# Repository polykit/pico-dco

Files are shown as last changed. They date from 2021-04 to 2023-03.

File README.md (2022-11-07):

# Raspberry Pi Pico Polyphonic DCO

This repository contains source code, schematics and PCB for a digitally controlled oscillator (DCO) with up to 6 voices which are driven by a Raspberry Pi Pico. It uses PIO to generate a highly accurate frequency which is controlled by USB or serial MIDI. The analog oscillator part is based on the Juno 106 and generates sawtooth and square wave signal with a 10Vpp amplitude. Amplitude compensation is done by a smoothed PWM signal coming from the Pico.

## Key features

- Digitally controlled analog oscillator using a Raspberry Pi Pico
- Up to six voices
- Voice stacking
- Detuning of voices
- Frequency modulation (FM)
- Separate gate signal
- DIN MIDI serial input
- USB MIDI input
- MIDI pitch bend
- Portamento with adjustable speed

This is how it sounds: [Ramp sample](https://soundcloud.com/polykit/pico-dco-ramp) [Pulse sample](https://soundcloud.com/polykit/pico-dco-pulse) [Polyphonic sample](https://soundcloud.com/polykit/pico-dco-polyphonic)

I use the DCO in my Polykit-6 polyphonic synthesizer, see https://www.youtube.com/watch?v=vj-DSh6yfM0 and https://www.youtube.com/watch?v=go1mErOdtsU

## Schematics and PCB

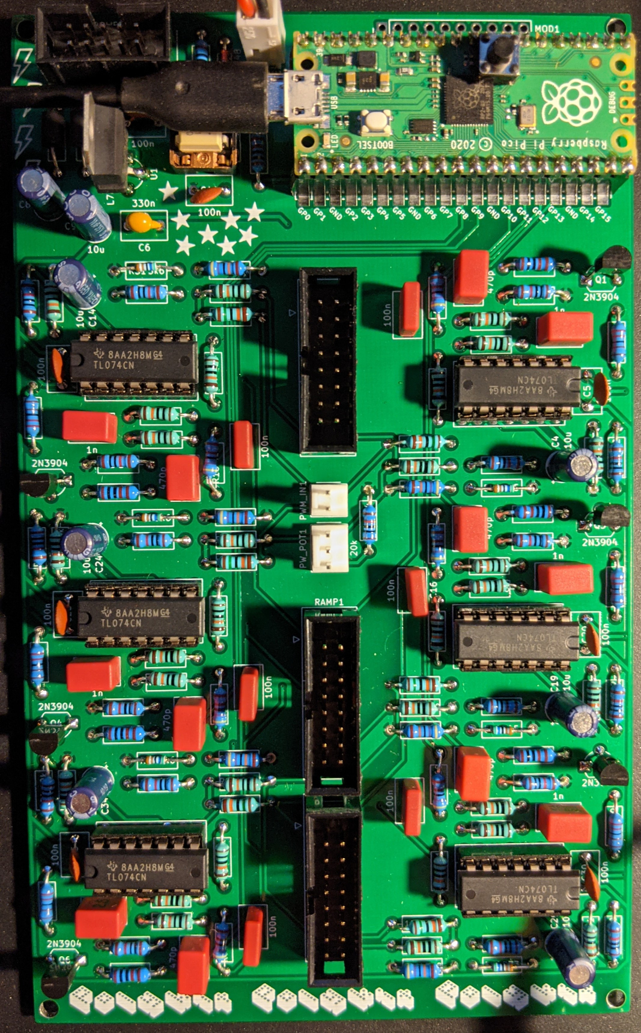
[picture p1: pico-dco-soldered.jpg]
Raspberry Pi Pico DCO Soldered


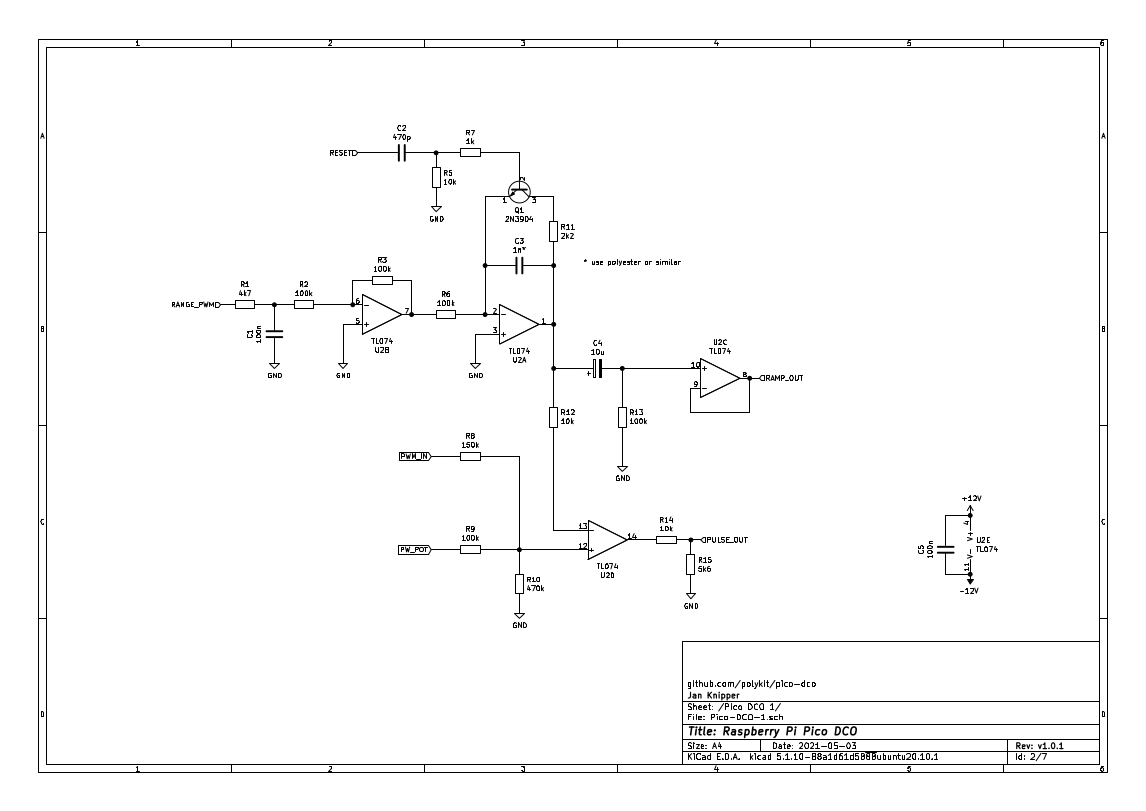
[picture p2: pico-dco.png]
Raspberry Pi Pico DCO


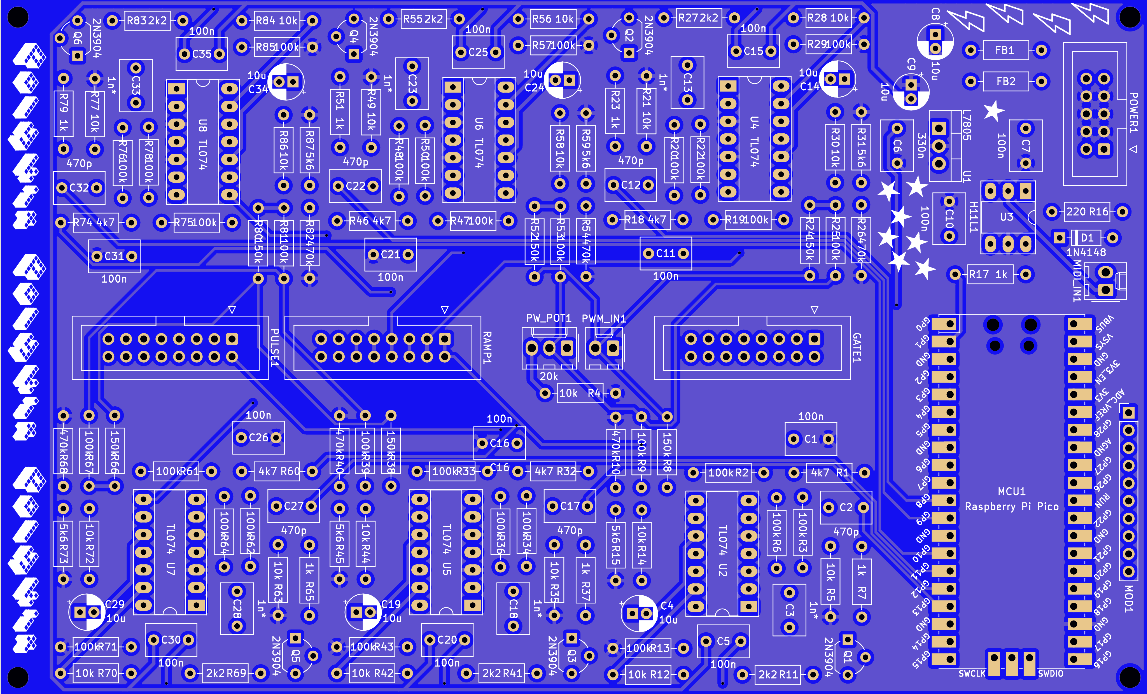
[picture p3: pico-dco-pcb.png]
Raspberry Pi Pico DCO PCB


Gerber files for the PCB can be found [here](kicad/plots).

## Installation (simple)

Press `BOOTSEL` button on the Pico while powering it with USB. Copy file `build/pico-dco.uf2` onto the USB mass storage device.

## Usage

After installing the Pico should register as USB MIDI device. Alternatively serial MIDI input is available. The DCO listens to note on/note off messages on MIDI channel 1. Pitch bend is also supported. Portamento can be enabled by MIDI CC message #65, portamento time can be adjusted by CC message #5.

## Detuning, stacking and FM

The build-in analog-to-digital converter can be used to modulate these parameters. You can add an external control voltage (0-3.3V) to that input pins. These features can be disabled by commenting (`//`) the following lines:

```
#define USE_ADC_STACK_VOICES // gpio 28 (adc 2)
#define USE_ADC_DETUNE       // gpio 27 (adc 1)
#define USE_ADC_FM           // gpio 26 (adc 0)
```

## References

https://blog.thea.codes/the-design-of-the-juno-dco/

https://electricdruid.net/roland-juno-dcos/

https://www.youtube.com/watch?v=yYnQYF_Xa8g

https://github.com/raspberrypi/pico-examples/tree/master/pio/pwm

https://github.com/raspberrypi/pico-examples/tree/master/pio/pio_blink

https://github.com/raspberrypi/pico-examples/tree/master/pwm/hello_pwm

https://qiita.com/jamjam/items/f2fdd5c072ff348fd809

https://github.com/infovore/pico-example-midi

https://learn.sparkfun.com/tutorials/midi-tutorial/all

http://www.music-software-development.com/midi-tutorial.html

http://midi.teragonaudio.com/tech/midispec/run.htm

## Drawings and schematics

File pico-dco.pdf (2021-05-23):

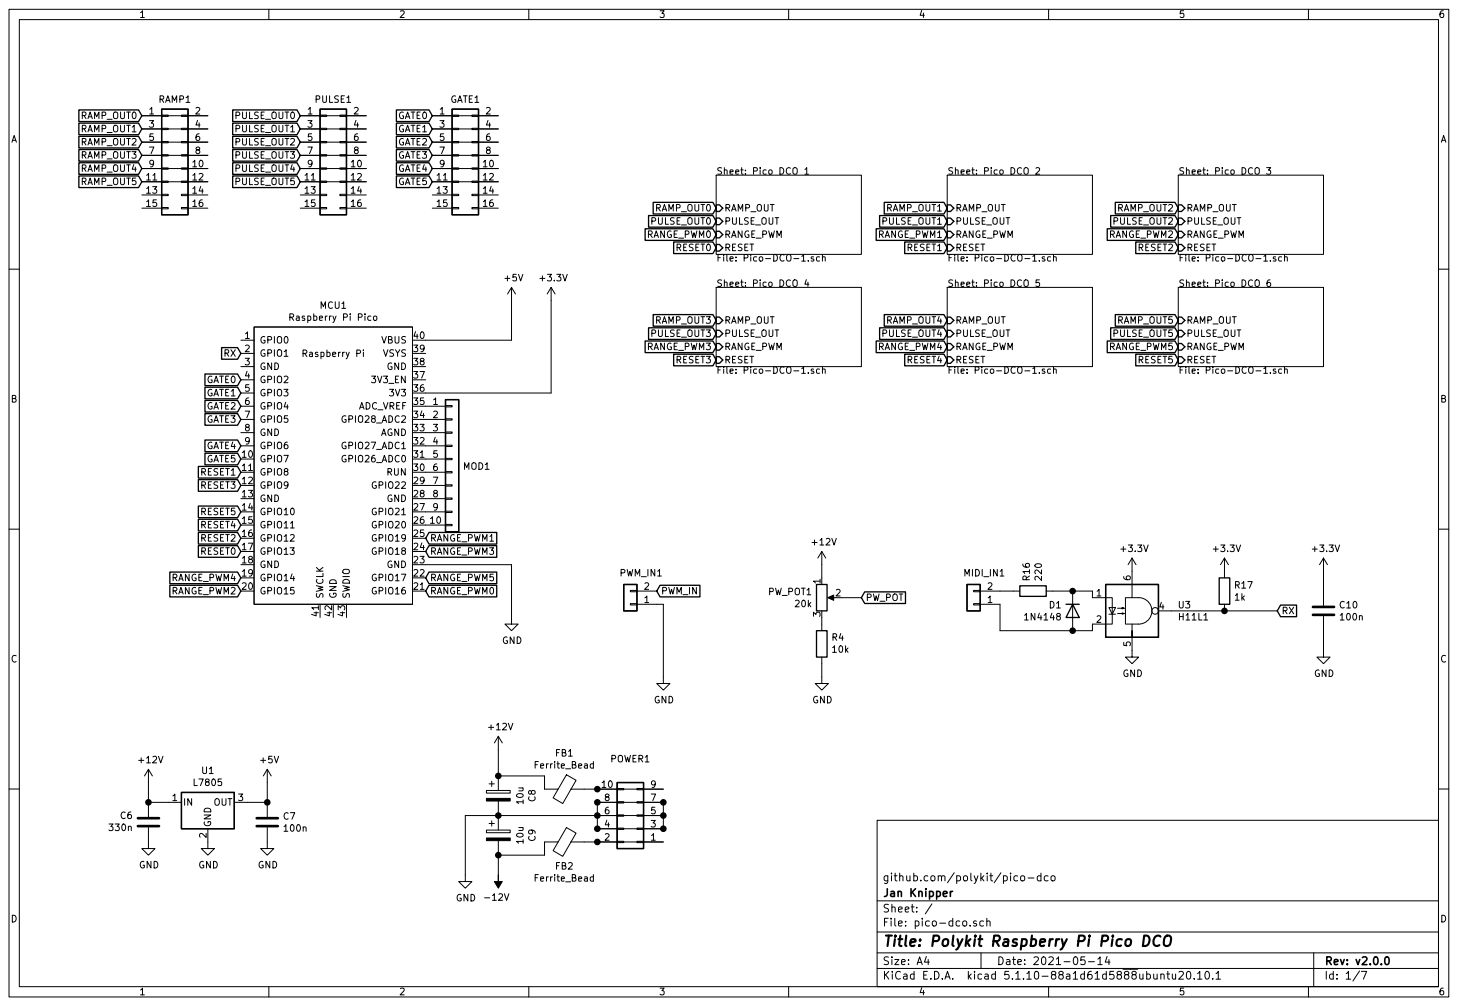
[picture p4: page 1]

RESET Sheet: Pico DCO 1 File: Pico-DCO-1.sch RAMP_OUT PULSE_OUT RANGE_PWM

RESET Sheet: Pico DCO 2 File: Pico-DCO-1.sch RAMP_OUT PULSE_OUT RANGE_PWM

RESET Sheet: Pico DCO 4 File: Pico-DCO-1.sch RAMP_OUT PULSE_OUT RANGE_PWM

RESET Sheet: Pico DCO 5 File: Pico-DCO-1.sch RAMP_OUT PULSE_OUT RANGE_PWM

Sheet: Pico DCO 6 File: Pico-DCO-1.sch RAMP_OUT PULSE_OUT RANGE_PWM

github.com/polykit/pico-dco
File: pico-dco.sch Sheet: / Jan Knipper

Id: 1/7 Title: Polykit Raspberry Pi Pico DCO

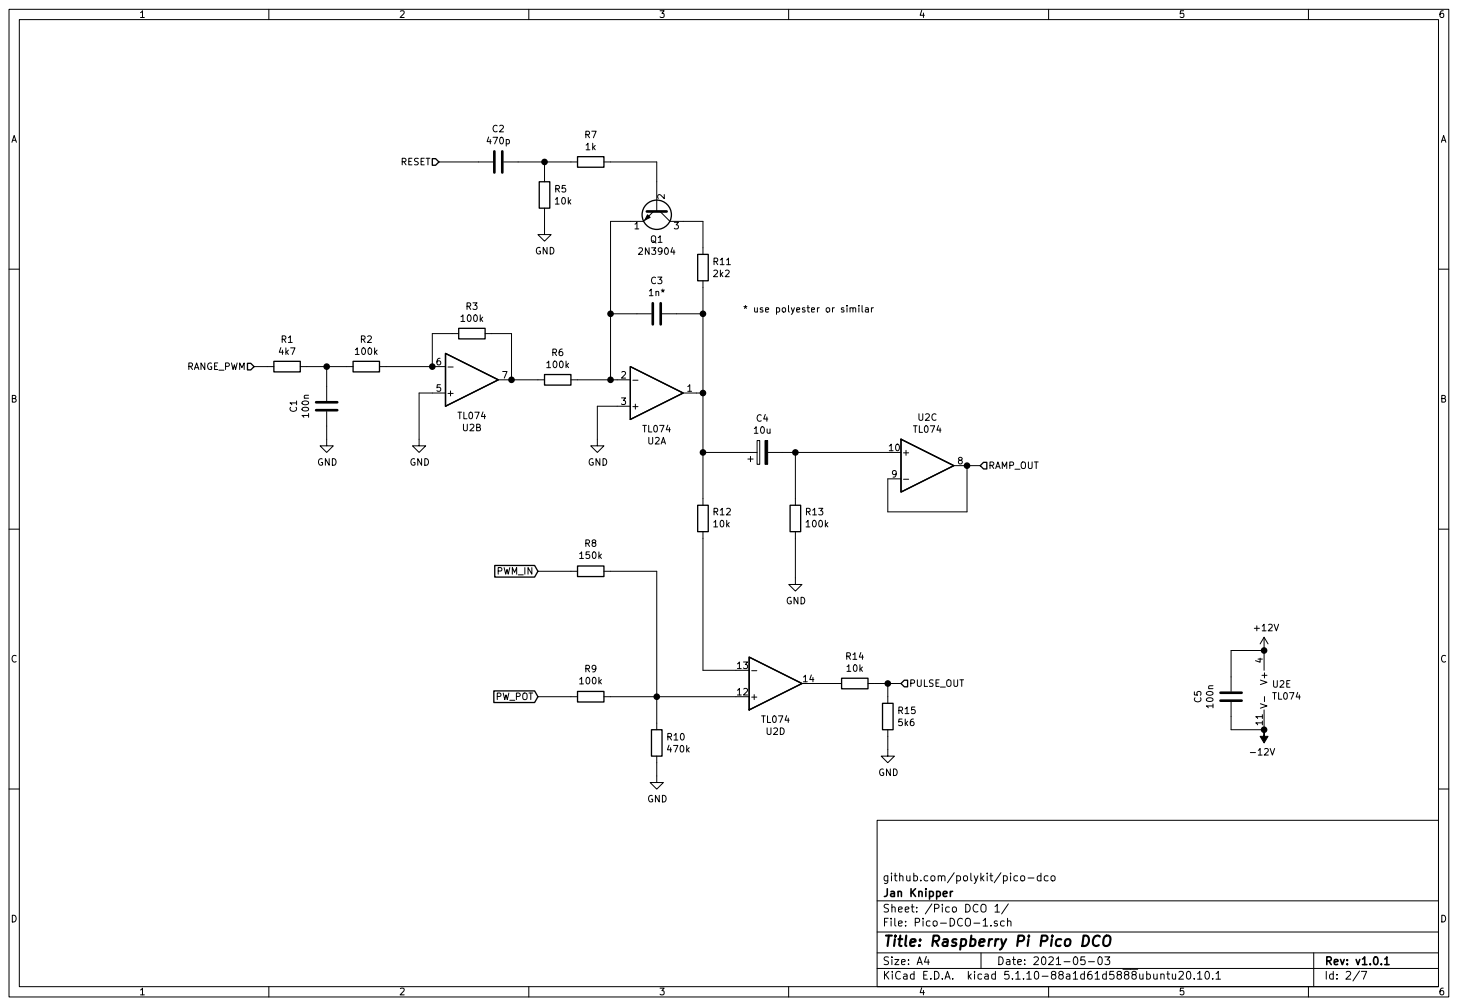
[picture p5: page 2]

* use polyester or similar

github.com/polykit/pico-dco R8

File: Pico-DCO-1.sch Sheet: /Pico DCO 1/ Jan Knipper

Id: 2/7 Title: Raspberry Pi Pico DCO

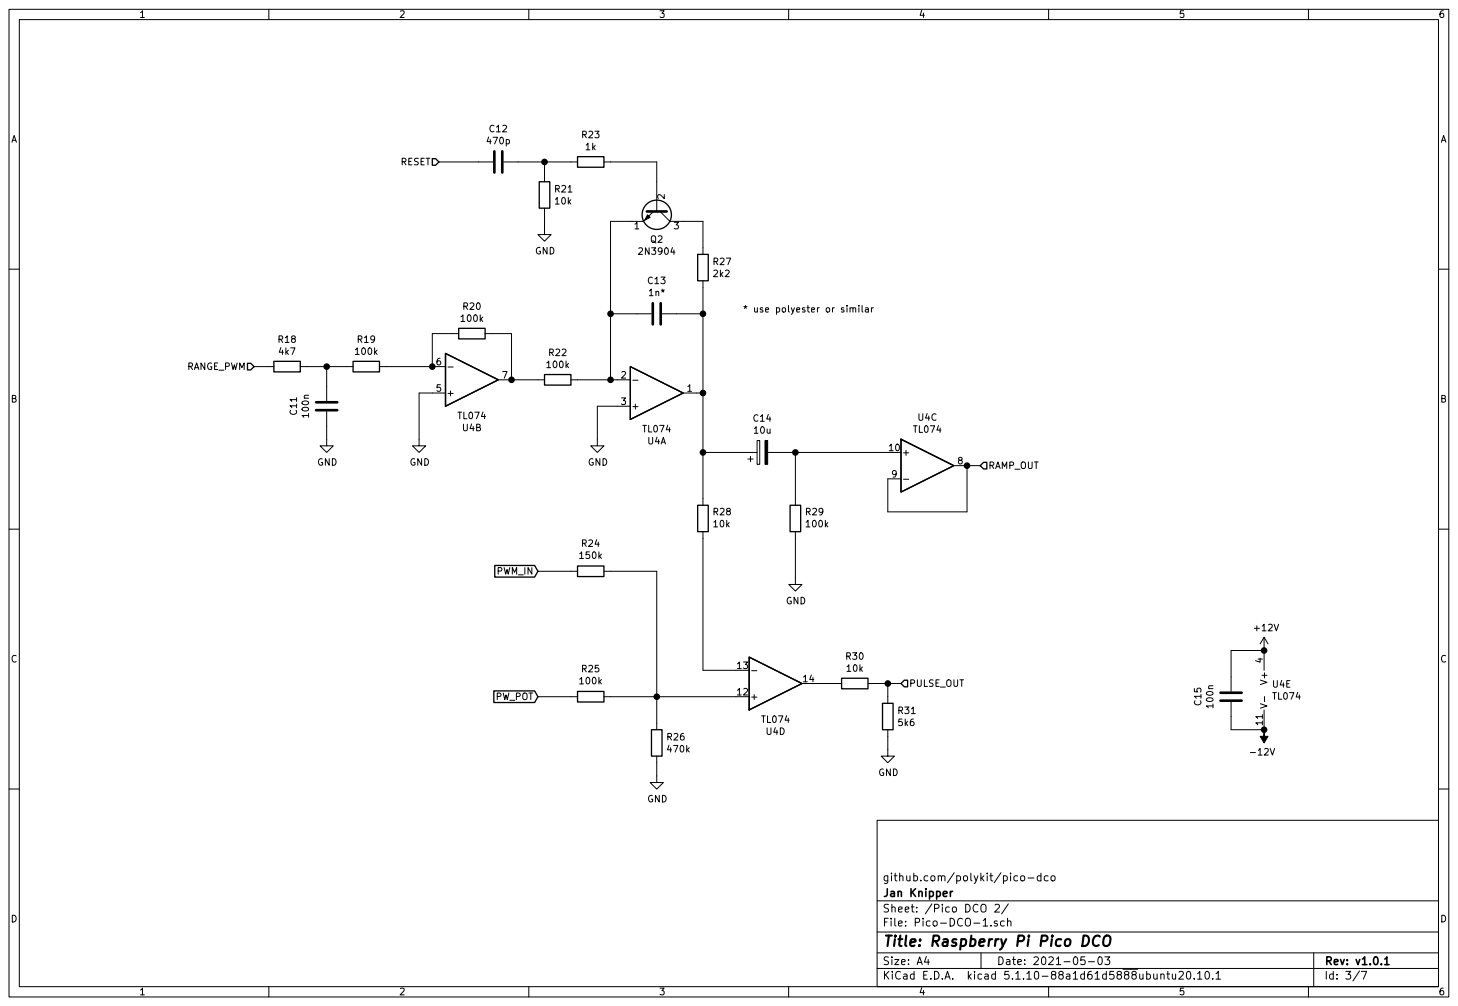
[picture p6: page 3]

* use polyester or similar

github.com/polykit/pico-dco R24

File: Pico-DCO-1.sch Sheet: /Pico DCO 2/ Jan Knipper

Id: 3/7 Title: Raspberry Pi Pico DCO

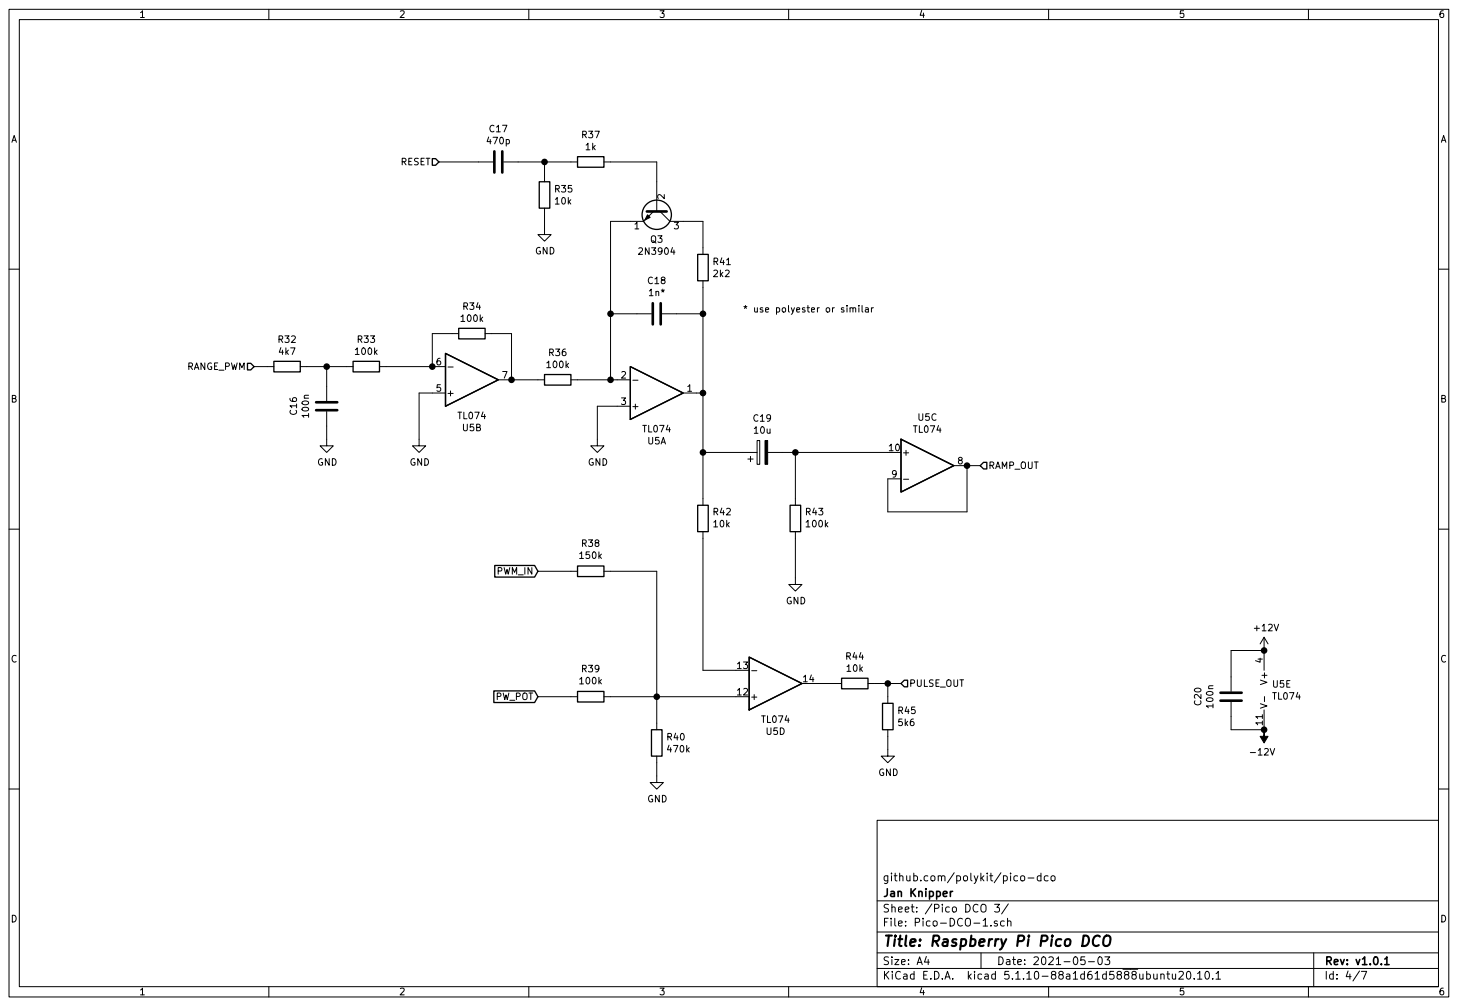
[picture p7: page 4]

* use polyester or similar

github.com/polykit/pico-dco R38

File: Pico-DCO-1.sch Sheet: /Pico DCO 3/ Jan Knipper

Id: 4/7 Title: Raspberry Pi Pico DCO

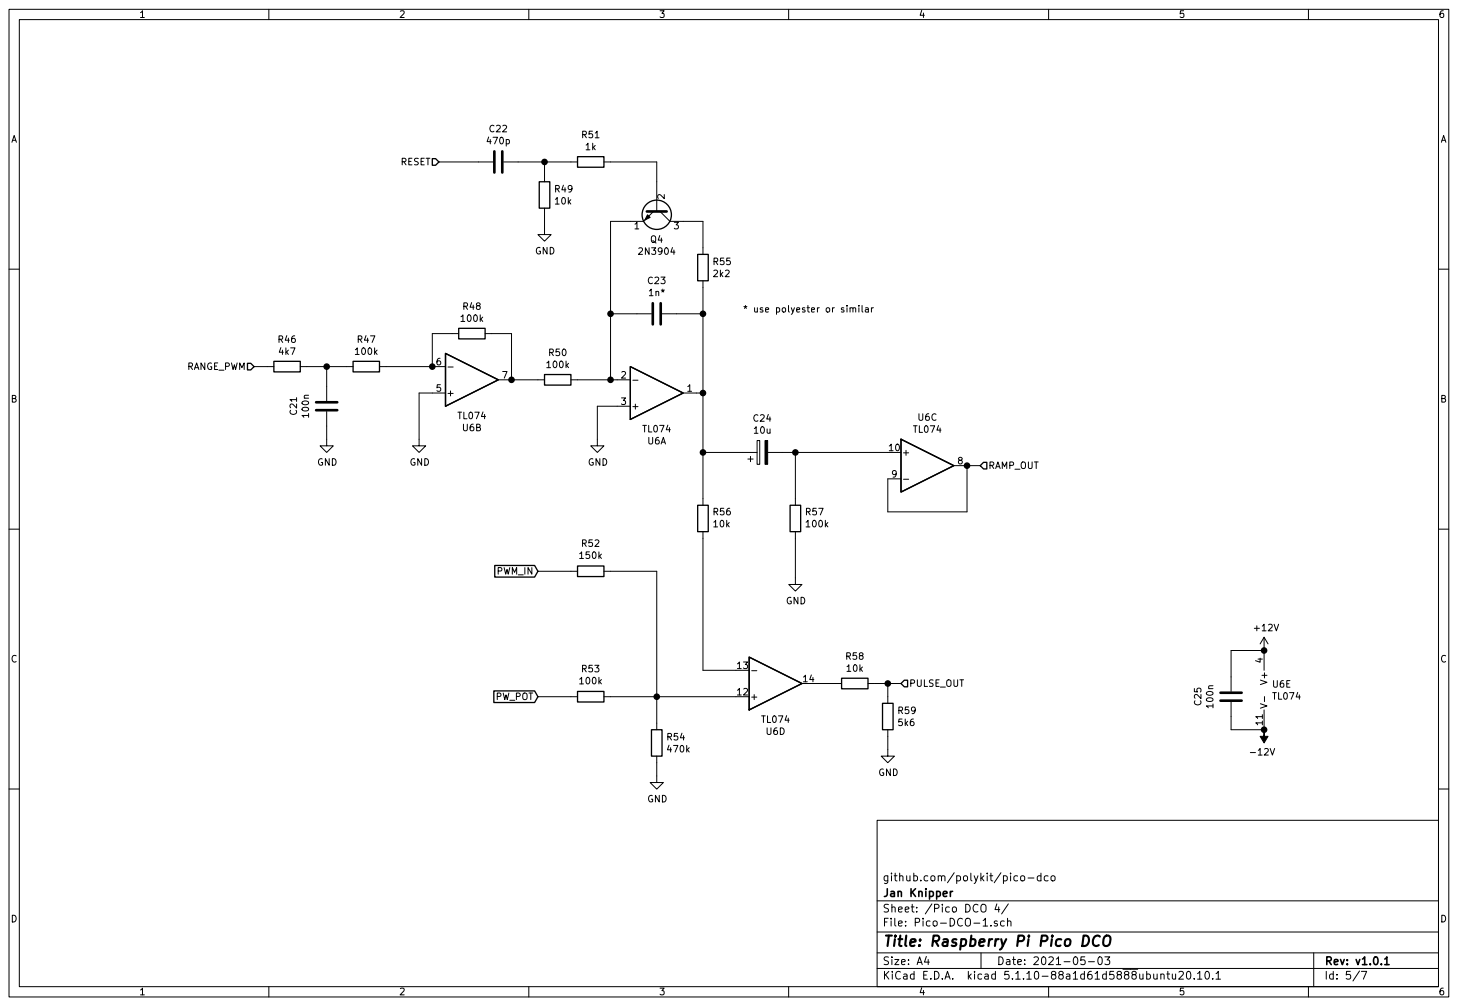
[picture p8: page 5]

* use polyester or similar

github.com/polykit/pico-dco R52

File: Pico-DCO-1.sch Sheet: /Pico DCO 4/ Jan Knipper

Id: 5/7 Title: Raspberry Pi Pico DCO

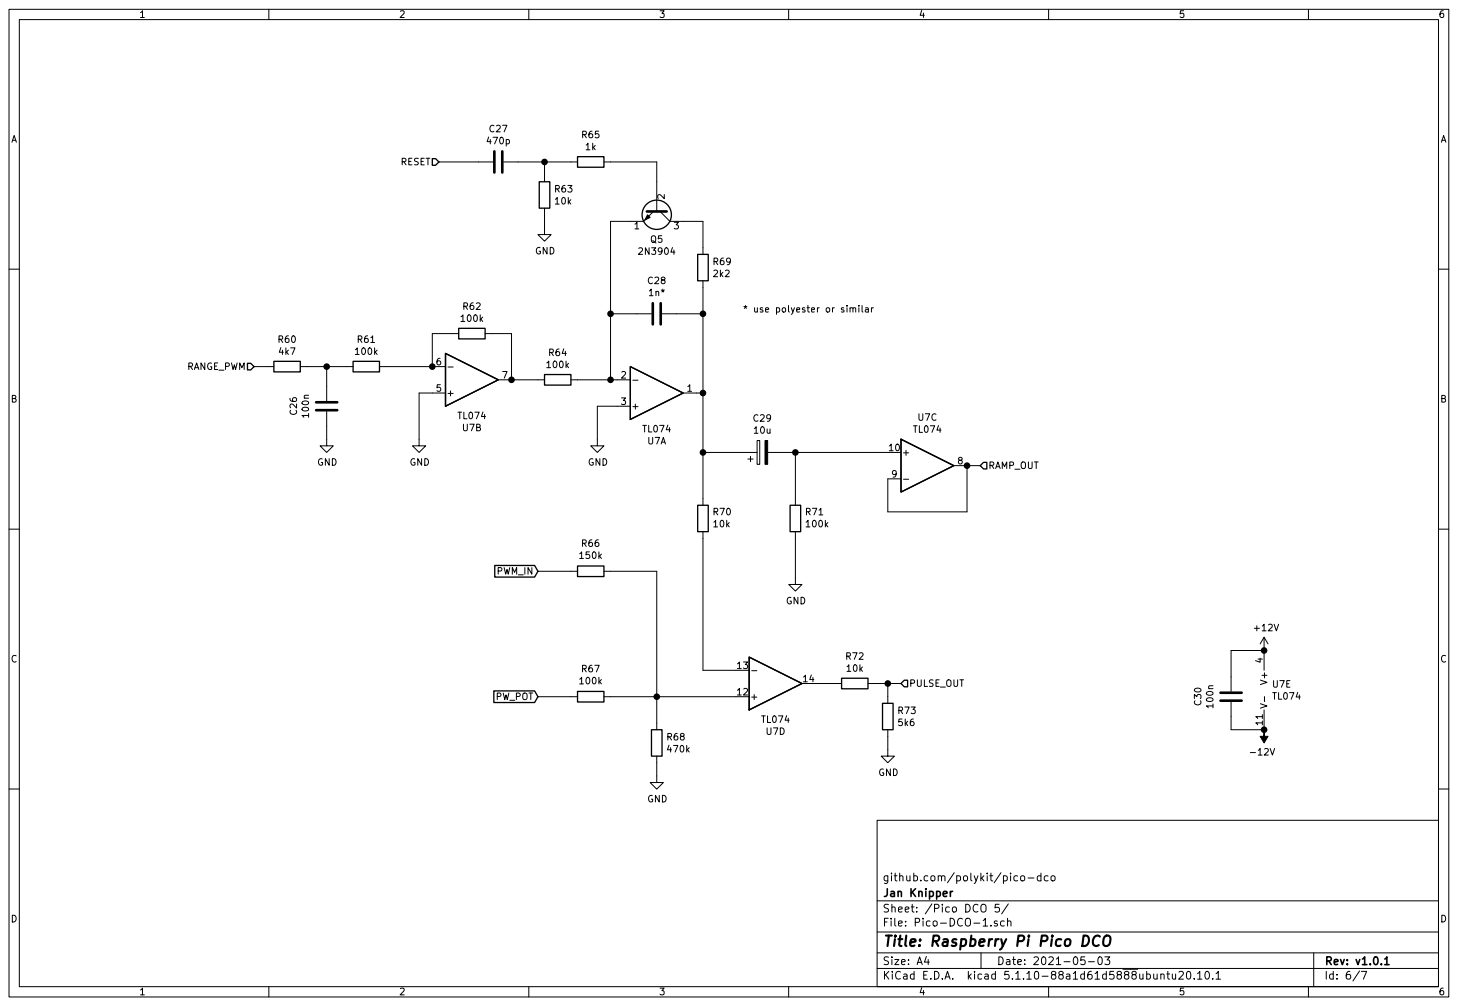
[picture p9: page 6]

* use polyester or similar

github.com/polykit/pico-dco R66

File: Pico-DCO-1.sch Sheet: /Pico DCO 5/ Jan Knipper

Id: 6/7 Title: Raspberry Pi Pico DCO

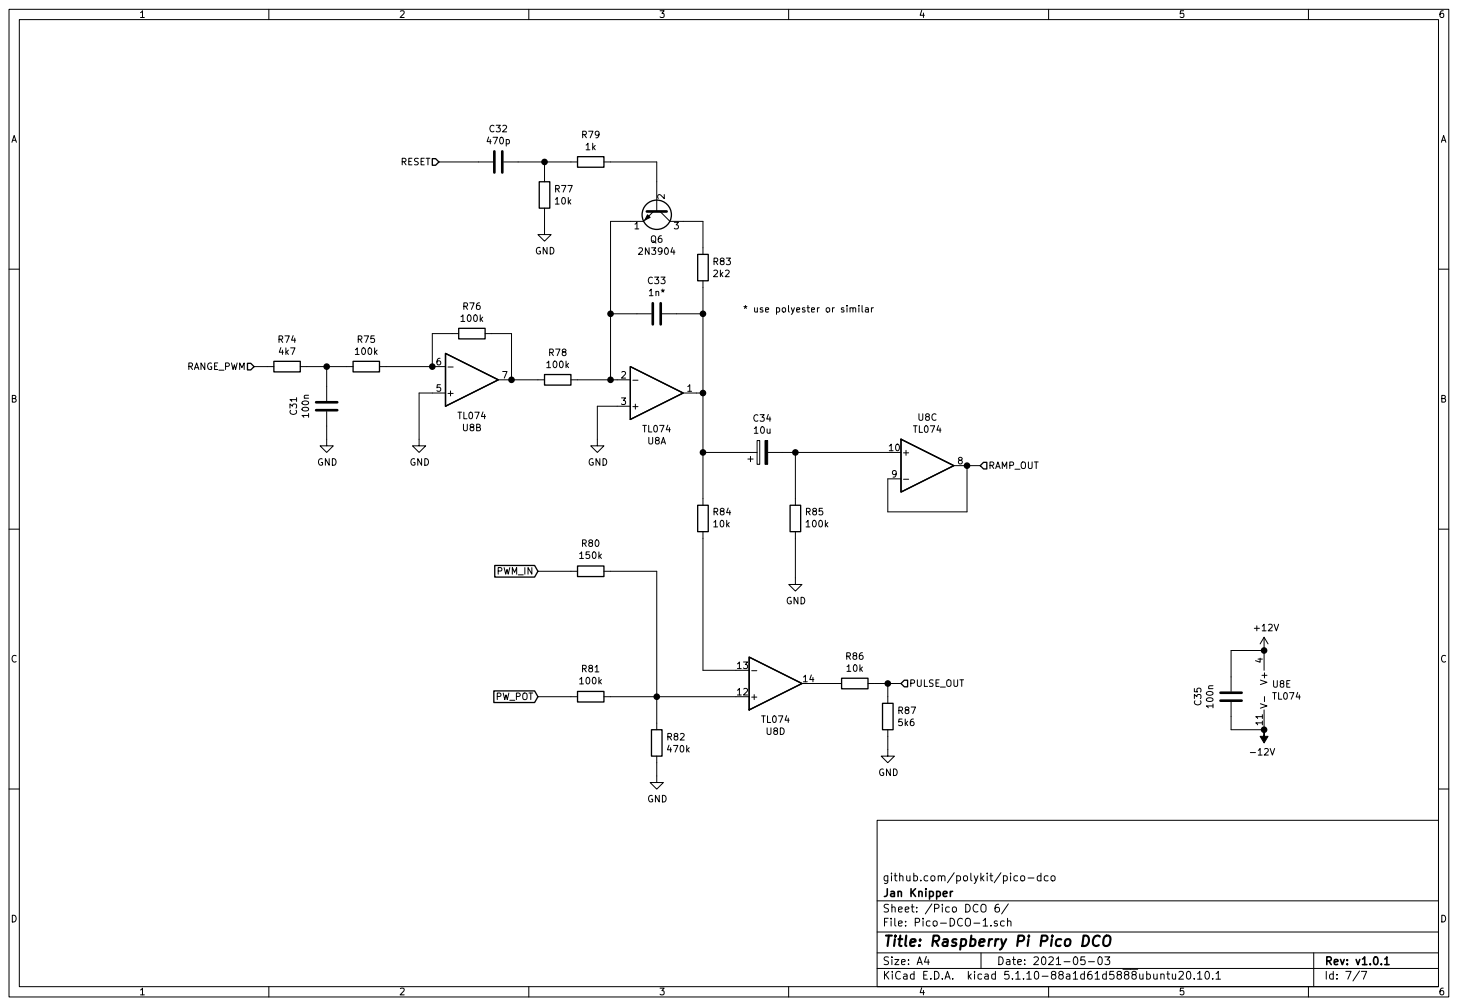
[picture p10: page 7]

* use polyester or similar

github.com/polykit/pico-dco R80

File: Pico-DCO-1.sch Sheet: /Pico DCO 6/ Jan Knipper

Id: 7/7 Title: Raspberry Pi Pico DCO

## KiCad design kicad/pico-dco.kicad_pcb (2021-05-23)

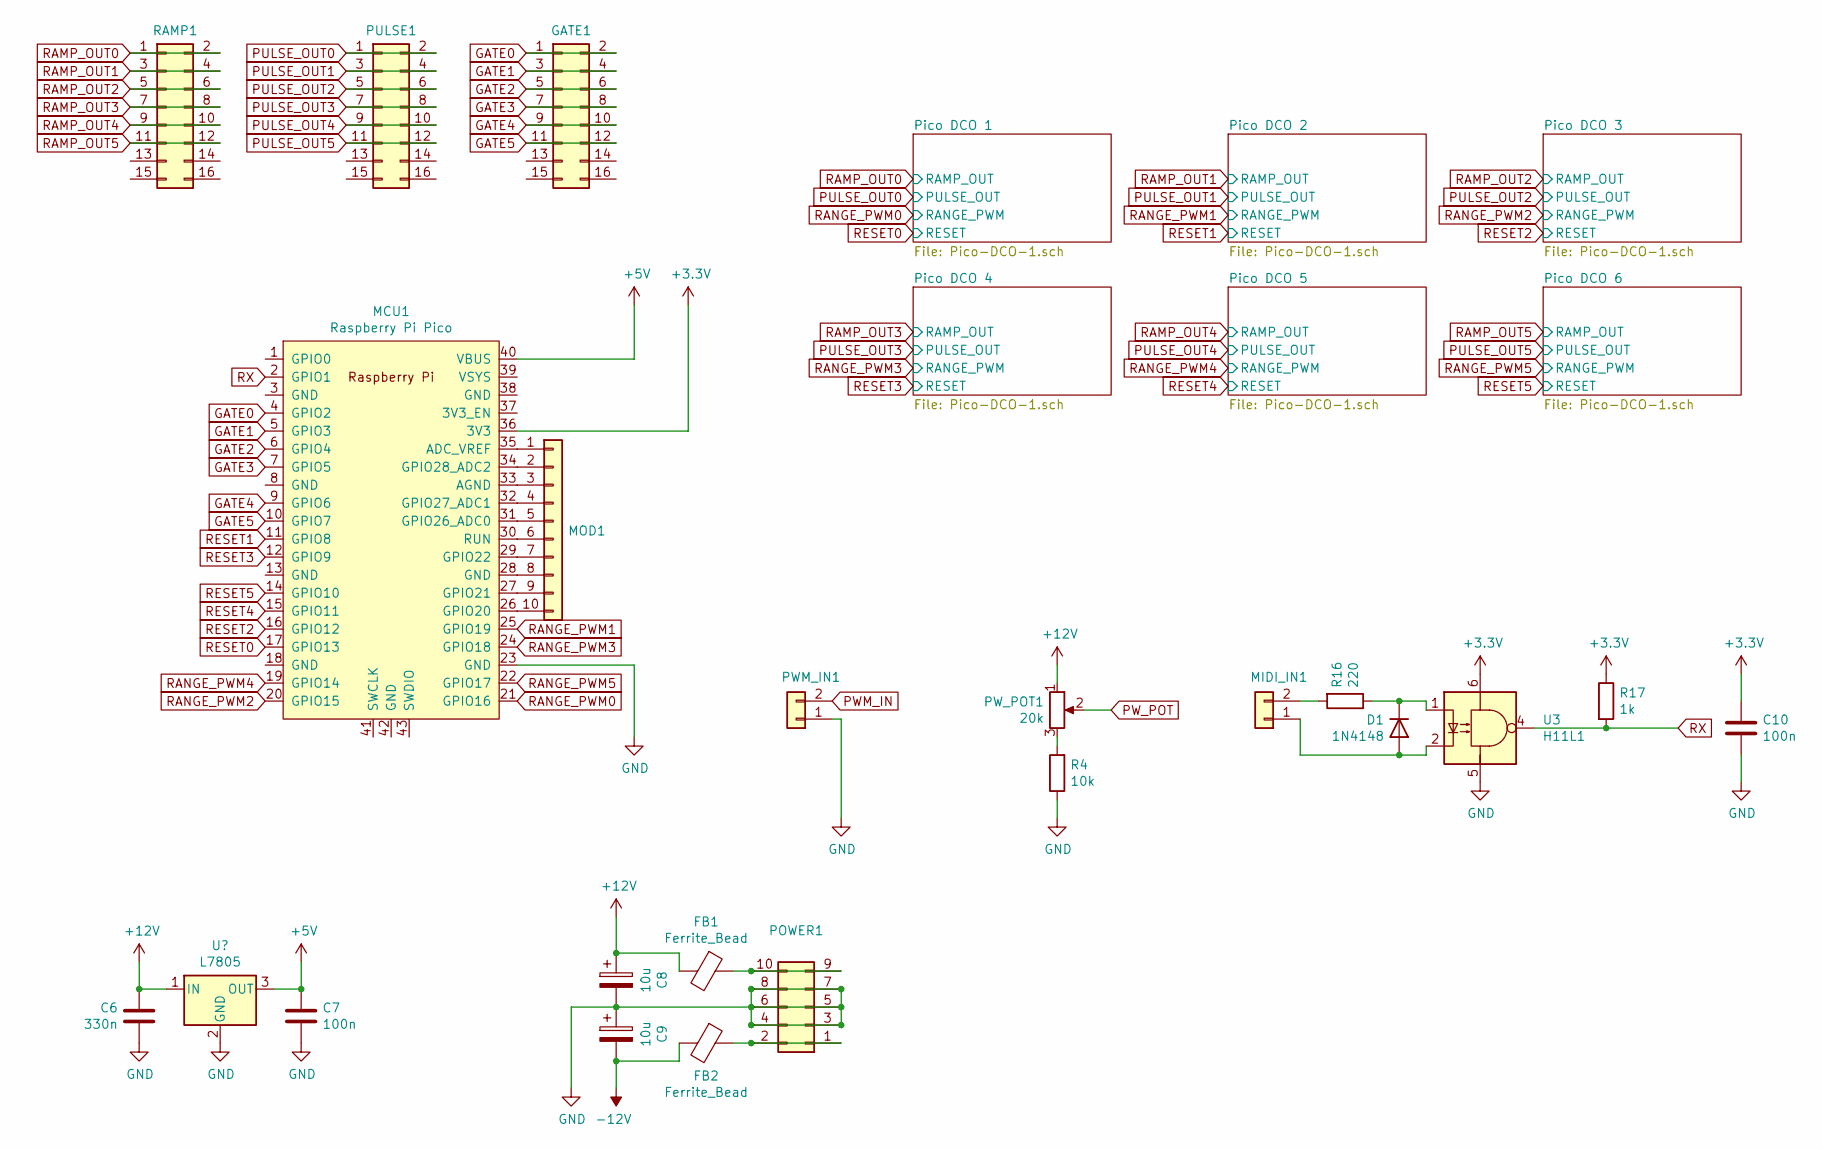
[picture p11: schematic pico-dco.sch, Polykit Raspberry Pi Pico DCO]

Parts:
C6: 330n; C_Rect_L7.2mm_W4.5mm_P5.00mm_FKS2_FKP2_MKS2_MKP2
C7, C10: 100n; C_Rect_L7.2mm_W4.5mm_P5.00mm_FKS2_FKP2_MKS2_MKP2
C8, C9: 10u; CP_Radial_D5.0mm_P2.00mm
D1: 1N4148; D_DO-35_SOD27_P7.62mm_Horizontal
FB1, FB2: Ferrite_Bead; R_Axial_DIN0207_L6.3mm_D2.5mm_P10.16mm_Horizontal
GATE1: Conn_02x08_Odd_Even; IDC-Header_2x08_P2.54mm_Vertical
MCU1: Raspberry Pi Pico; RPi_Pico_SMD_TH
MIDI_IN1: Conn_01x02; Molex_KK-254_AE-6410-02A_1x02_P2.54mm_Vertical
MOD1: Conn_01x10; PinHeader_1x10_P2.54mm_Vertical
POWER1: Conn_02x05_Odd_Even; IDC-Header_2x05_P2.54mm_Vertical
PULSE1: Conn_02x08_Odd_Even; IDC-Header_2x08_P2.54mm_Vertical
PWM_IN1: Conn_01x02; Molex_KK-254_AE-6410-02A_1x02_P2.54mm_Vertical
PW_POT1: 20k; Molex_KK-254_AE-6410-03A_1x03_P2.54mm_Vertical
R4: 10k; R_Axial_DIN0207_L6.3mm_D2.5mm_P10.16mm_Horizontal
R16: 220; R_Axial_DIN0207_L6.3mm_D2.5mm_P10.16mm_Horizontal
R17: 1k; R_Axial_DIN0207_L6.3mm_D2.5mm_P10.16mm_Horizontal
RAMP1: Conn_02x08_Odd_Even; IDC-Header_2x08_P2.54mm_Vertical
U3: H11L1; DIP-6_W7.62mm_Socket_LongPads

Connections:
+3V3: C10.1, MCU1.36 (3V3), R17.1, U3.6
+5V: C7.1, MCU1.40 (VBUS); also elsewhere on the board
+12V: C6.2, C8.1, FB1.2, PW_POT1.1; also elsewhere on the board
-12V: C9.2, FB2.2; also elsewhere on the board
GATE0: GATE1.1, GATE1.2, MCU1.4 (GPIO2)
GATE1: GATE1.3, GATE1.4, MCU1.5 (GPIO3)
GATE2: GATE1.5, GATE1.6, MCU1.6 (GPIO4)
GATE3: GATE1.7, GATE1.8, MCU1.7 (GPIO5)
GATE4: GATE1.9, GATE1.10, MCU1.9 (GPIO6)
GATE5: GATE1.11, GATE1.12, MCU1.10 (GPIO7)
GND: C6.1, C7.2, C8.2, C9.1, C10.2, MCU1.23 (GND), POWER1.3, POWER1.4, POWER1.5, POWER1.6, POWER1.7, POWER1.8, PWM_IN1.1, R4.1, U3.5; also elsewhere on the board
unnamed: D1.1 (K), R16.1, U3.1
unnamed: D1.2 (A), MIDI_IN1.1, U3.2
unnamed: FB1.1, POWER1.9, POWER1.10
unnamed: FB2.1, POWER1.1, POWER1.2
unnamed: MCU1.26 (GPIO20), MOD1.10
unnamed: MCU1.27 (GPIO21), MOD1.9
unnamed: MCU1.28 (GND), MOD1.8
unnamed: MCU1.29 (GPIO22), MOD1.7
unnamed: MCU1.30 (RUN), MOD1.6
unnamed: MCU1.31 (GPIO26_ADC0), MOD1.5
unnamed: MCU1.32 (GPIO27_ADC1), MOD1.4
unnamed: MCU1.33 (AGND), MOD1.3
unnamed: MCU1.34 (GPIO28_ADC2), MOD1.2
unnamed: MCU1.35 (ADC_VREF), MOD1.1
unnamed: MIDI_IN1.2, R16.2
unnamed: PW_POT1.3, R4.2
PULSE_OUT0: PULSE1.1, PULSE1.2; also elsewhere on the board
PULSE_OUT1: PULSE1.3, PULSE1.4; also elsewhere on the board
PULSE_OUT2: PULSE1.5, PULSE1.6; also elsewhere on the board
PULSE_OUT3: PULSE1.7, PULSE1.8; also elsewhere on the board
PULSE_OUT4: PULSE1.9, PULSE1.10; also elsewhere on the board
PULSE_OUT5: PULSE1.11, PULSE1.12; also elsewhere on the board
PWM_IN: PWM_IN1.2; also elsewhere on the board
PW_POT: PW_POT1.2; also elsewhere on the board
RAMP_OUT0: RAMP1.1, RAMP1.2; also elsewhere on the board
RAMP_OUT1: RAMP1.3, RAMP1.4; also elsewhere on the board
RAMP_OUT2: RAMP1.5, RAMP1.6; also elsewhere on the board
RAMP_OUT3: RAMP1.7, RAMP1.8; also elsewhere on the board
RAMP_OUT4: RAMP1.9, RAMP1.10; also elsewhere on the board
RAMP_OUT5: RAMP1.11, RAMP1.12; also elsewhere on the board
RANGE_PWM0: MCU1.21 (GPIO16); also elsewhere on the board
RANGE_PWM1: MCU1.25 (GPIO19); also elsewhere on the board
RANGE_PWM2: MCU1.20 (GPIO15); also elsewhere on the board
RANGE_PWM3: MCU1.24 (GPIO18); also elsewhere on the board
RANGE_PWM4: MCU1.19 (GPIO14); also elsewhere on the board
RANGE_PWM5: MCU1.22 (GPIO17); also elsewhere on the board
RESET0: MCU1.17 (GPIO13); also elsewhere on the board
RESET1: MCU1.11 (GPIO8); also elsewhere on the board
RESET2: MCU1.16 (GPIO12); also elsewhere on the board
RESET3: MCU1.12 (GPIO9); also elsewhere on the board
RESET4: MCU1.15 (GPIO11); also elsewhere on the board
RESET5: MCU1.14 (GPIO10); also elsewhere on the board
RX: MCU1.2 (GPIO1), R17.2, U3.4

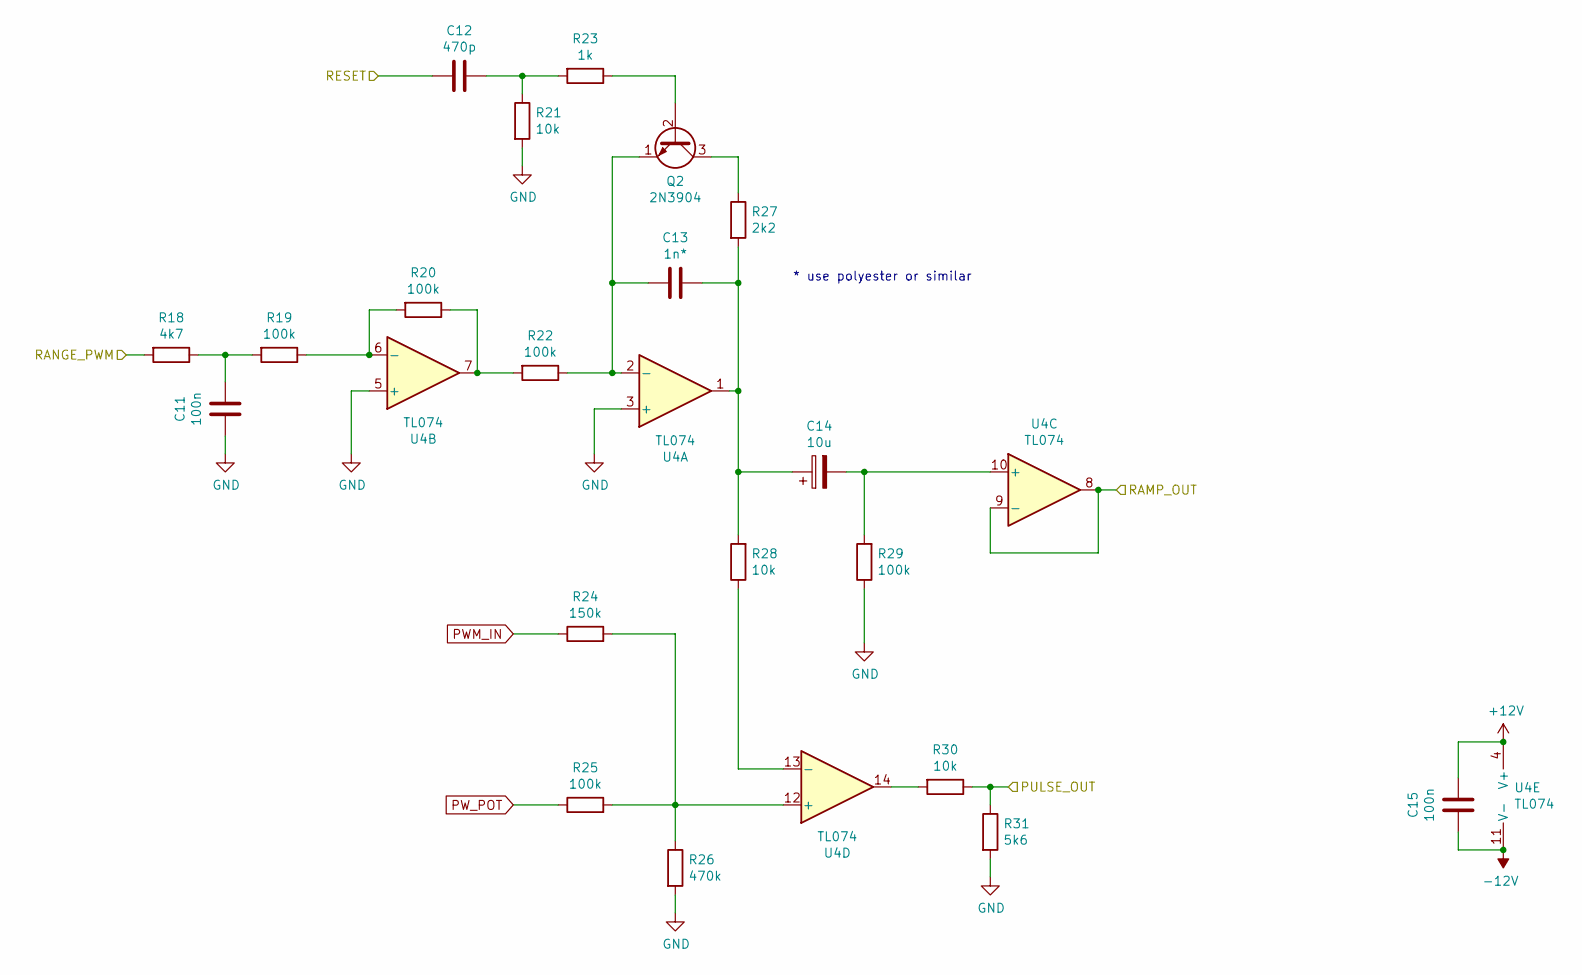
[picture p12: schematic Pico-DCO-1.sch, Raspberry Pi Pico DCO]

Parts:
C1, C5: 100n; C_Rect_L7.2mm_W4.5mm_P5.00mm_FKS2_FKP2_MKS2_MKP2
C2: 470p; C_Rect_L7.2mm_W4.5mm_P5.00mm_FKS2_FKP2_MKS2_MKP2
C3: 1n*; C_Rect_L7.2mm_W4.5mm_P5.00mm_FKS2_FKP2_MKS2_MKP2
C4: 10u; CP_Radial_D5.0mm_P2.00mm
Q1: 2N3904; TO-92_Wide
R1: 4k7; R_Axial_DIN0207_L6.3mm_D2.5mm_P10.16mm_Horizontal
R2, R3, R6, R9, R13: 100k; R_Axial_DIN0207_L6.3mm_D2.5mm_P10.16mm_Horizontal
R5, R12, R14: 10k; R_Axial_DIN0207_L6.3mm_D2.5mm_P10.16mm_Horizontal
R7: 1k; R_Axial_DIN0207_L6.3mm_D2.5mm_P10.16mm_Horizontal
R8: 150k; R_Axial_DIN0207_L6.3mm_D2.5mm_P10.16mm_Horizontal
R10: 470k; R_Axial_DIN0207_L6.3mm_D2.5mm_P10.16mm_Horizontal
R11: 2k2; R_Axial_DIN0207_L6.3mm_D2.5mm_P10.16mm_Horizontal
R15: 5k6; R_Axial_DIN0207_L6.3mm_D2.5mm_P10.16mm_Horizontal
U2: TL074; DIP-14_W7.62mm_Socket_LongPads

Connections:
+12V: C5.1, U2.4 (V+); also elsewhere on the board
-12V: C5.2, U2.11 (V-); also elsewhere on the board
GND: C1.2, R5.2, R10.2, R13.1, R15.2, U2.3 (+), U2.5 (+); also elsewhere on the board
unnamed: C1.1, R1.1, R2.2
unnamed: C2.1, R5.1, R7.2
unnamed: C3.1, C4.1, R11.2, R12.2, U2.1
unnamed: C3.2, Q1.1 (E), R6.1, U2.2 (-)
unnamed: C4.2, R13.2, U2.10 (+)
unnamed: Q1.2 (B), R7.1
unnamed: Q1.3 (C), R11.1
unnamed: R2.1, R3.2, U2.6 (-)
unnamed: R3.1, R6.2, U2.7
unnamed: R8.2, R9.2, R10.1, U2.12 (+)
unnamed: R12.1, U2.13 (-)
unnamed: R14.2, U2.14
PULSE_OUT0: R14.1, R15.1; also elsewhere on the board
PWM_IN: R8.1; also elsewhere on the board
PW_POT: R9.1; also elsewhere on the board
RAMP_OUT0: U2.8, U2.9 (-); also elsewhere on the board
RANGE_PWM0: R1.2; also elsewhere on the board
RESET0: C2.2; also elsewhere on the board

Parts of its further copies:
C11, C15, C16, C20, C21, C25, C26, C30, C31, C35: 100n; C_Rect_L7.2mm_W4.5mm_P5.00mm_FKS2_FKP2_MKS2_MKP2
C12, C17, C22, C27, C32: 470p; C_Rect_L7.2mm_W4.5mm_P5.00mm_FKS2_FKP2_MKS2_MKP2
C13, C18, C23, C28, C33: 1n*; C_Rect_L7.2mm_W4.5mm_P5.00mm_FKS2_FKP2_MKS2_MKP2
C14, C19, C24, C29, C34: 10u; CP_Radial_D5.0mm_P2.00mm
Q2, Q3, Q4, Q5, Q6: 2N3904; TO-92_Wide
R18, R32, R46, R60, R74: 4k7; R_Axial_DIN0207_L6.3mm_D2.5mm_P10.16mm_Horizontal
R19, R20, R22, R25, R29, R33, R34, R36, R39, R43, R47, R48, R50, R53, R57, R61, R62, R64, R67, R71, R75, R76, R78, R81, R85: 100k; R_Axial_DIN0207_L6.3mm_D2.5mm_P10.16mm_Horizontal
R21, R28, R30, R35, R42, R44, R49, R56, R58, R63, R70, R72, R77, R84, R86: 10k; R_Axial_DIN0207_L6.3mm_D2.5mm_P10.16mm_Horizontal
R23, R37, R51, R65, R79: 1k; R_Axial_DIN0207_L6.3mm_D2.5mm_P10.16mm_Horizontal
R24, R38, R52, R66, R80: 150k; R_Axial_DIN0207_L6.3mm_D2.5mm_P10.16mm_Horizontal
R26, R40, R54, R68, R82: 470k; R_Axial_DIN0207_L6.3mm_D2.5mm_P10.16mm_Horizontal
R27, R41, R55, R69, R83: 2k2; R_Axial_DIN0207_L6.3mm_D2.5mm_P10.16mm_Horizontal
R31, R45, R59, R73, R87: 5k6; R_Axial_DIN0207_L6.3mm_D2.5mm_P10.16mm_Horizontal
U4, U5, U6, U7, U8: TL074; DIP-14_W7.62mm_Socket_LongPads

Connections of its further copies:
+12V: C15.1, C20.1, C25.1, C30.1, C35.1, U4.4 (V+), U5.4 (V+), U6.4 (V+), U7.4 (V+), U8.4 (V+); also elsewhere on the board
-12V: C15.2, C20.2, C25.2, C30.2, C35.2, U4.11 (V-), U5.11 (V-), U6.11 (V-), U7.11 (V-), U8.11 (V-); also elsewhere on the board
GND: C11.2, C16.2, C21.2, C26.2, C31.2, R21.2, R26.2, R29.1, R31.2, R35.2, R40.2, R43.1, R45.2, R49.2, R54.2, R57.1, R59.2, R63.2, R68.2, R71.1, R73.2, R77.2, R82.2, R85.1, R87.2, U4.3 (+), U4.5 (+), U5.3 (+), U5.5 (+), U6.3 (+), U6.5 (+), U7.3 (+), U7.5 (+), U8.3 (+), U8.5 (+); also elsewhere on the board
unnamed: C11.1, R18.1, R19.2
unnamed: C12.1, R21.1, R23.2
unnamed: C13.1, C14.1, R27.2, R28.2, U4.1
unnamed: C13.2, Q2.1 (E), R22.1, U4.2 (-)
unnamed: C14.2, R29.2, U4.10 (+)
unnamed: C16.1, R32.1, R33.2
unnamed: C17.1, R35.1, R37.2
unnamed: C18.1, C19.1, R41.2, R42.2, U5.1
unnamed: C18.2, Q3.1 (E), R36.1, U5.2 (-)
unnamed: C19.2, R43.2, U5.10 (+)
unnamed: C21.1, R46.1, R47.2
unnamed: C22.1, R49.1, R51.2
unnamed: C23.1, C24.1, R55.2, R56.2, U6.1
unnamed: C23.2, Q4.1 (E), R50.1, U6.2 (-)
unnamed: C24.2, R57.2, U6.10 (+)
unnamed: C26.1, R60.1, R61.2
unnamed: C27.1, R63.1, R65.2
unnamed: C28.1, C29.1, R69.2, R70.2, U7.1
unnamed: C28.2, Q5.1 (E), R64.1, U7.2 (-)
unnamed: C29.2, R71.2, U7.10 (+)
unnamed: C31.1, R74.1, R75.2
unnamed: C32.1, R77.1, R79.2
unnamed: C33.1, C34.1, R83.2, R84.2, U8.1
unnamed: C33.2, Q6.1 (E), R78.1, U8.2 (-)
unnamed: C34.2, R85.2, U8.10 (+)
unnamed: Q2.2 (B), R23.1
unnamed: Q2.3 (C), R27.1
unnamed: Q3.2 (B), R37.1
unnamed: Q3.3 (C), R41.1
unnamed: Q4.2 (B), R51.1
unnamed: Q4.3 (C), R55.1
unnamed: Q5.2 (B), R65.1
unnamed: Q5.3 (C), R69.1
unnamed: Q6.2 (B), R79.1
unnamed: Q6.3 (C), R83.1
unnamed: R19.1, R20.2, U4.6 (-)
unnamed: R20.1, R22.2, U4.7
unnamed: R24.2, R25.2, R26.1, U4.12 (+)
unnamed: R28.1, U4.13 (-)
unnamed: R30.2, U4.14
unnamed: R33.1, R34.2, U5.6 (-)
unnamed: R34.1, R36.2, U5.7
unnamed: R38.2, R39.2, R40.1, U5.12 (+)
unnamed: R42.1, U5.13 (-)
unnamed: R44.2, U5.14
unnamed: R47.1, R48.2, U6.6 (-)
unnamed: R48.1, R50.2, U6.7
unnamed: R52.2, R53.2, R54.1, U6.12 (+)
unnamed: R56.1, U6.13 (-)
unnamed: R58.2, U6.14
unnamed: R61.1, R62.2, U7.6 (-)
unnamed: R62.1, R64.2, U7.7
unnamed: R66.2, R67.2, R68.1, U7.12 (+)
unnamed: R70.1, U7.13 (-)
unnamed: R72.2, U7.14
unnamed: R75.1, R76.2, U8.6 (-)
unnamed: R76.1, R78.2, U8.7
unnamed: R80.2, R81.2, R82.1, U8.12 (+)
unnamed: R84.1, U8.13 (-)
unnamed: R86.2, U8.14
PULSE_OUT1: R30.1, R31.1; also elsewhere on the board
PULSE_OUT2: R44.1, R45.1; also elsewhere on the board
PULSE_OUT3: R58.1, R59.1; also elsewhere on the board
PULSE_OUT4: R72.1, R73.1; also elsewhere on the board
PULSE_OUT5: R86.1, R87.1; also elsewhere on the board
PWM_IN: R24.1, R38.1, R52.1, R66.1, R80.1; also elsewhere on the board
PW_POT: R25.1, R39.1, R53.1, R67.1, R81.1; also elsewhere on the board
RAMP_OUT1: U4.8, U4.9 (-); also elsewhere on the board
RAMP_OUT2: U5.8, U5.9 (-); also elsewhere on the board
RAMP_OUT3: U6.8, U6.9 (-); also elsewhere on the board
RAMP_OUT4: U7.8, U7.9 (-); also elsewhere on the board
RAMP_OUT5: U8.8, U8.9 (-); also elsewhere on the board
RANGE_PWM1: R18.2; also elsewhere on the board
RANGE_PWM2: R32.2; also elsewhere on the board
RANGE_PWM3: R46.2; also elsewhere on the board
RANGE_PWM4: R60.2; also elsewhere on the board
RANGE_PWM5: R74.2; also elsewhere on the board
RESET1: C12.2; also elsewhere on the board
RESET2: C17.2; also elsewhere on the board
RESET3: C22.2; also elsewhere on the board
RESET4: C27.2; also elsewhere on the board
RESET5: C32.2; also elsewhere on the board

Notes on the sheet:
* use polyester or similar

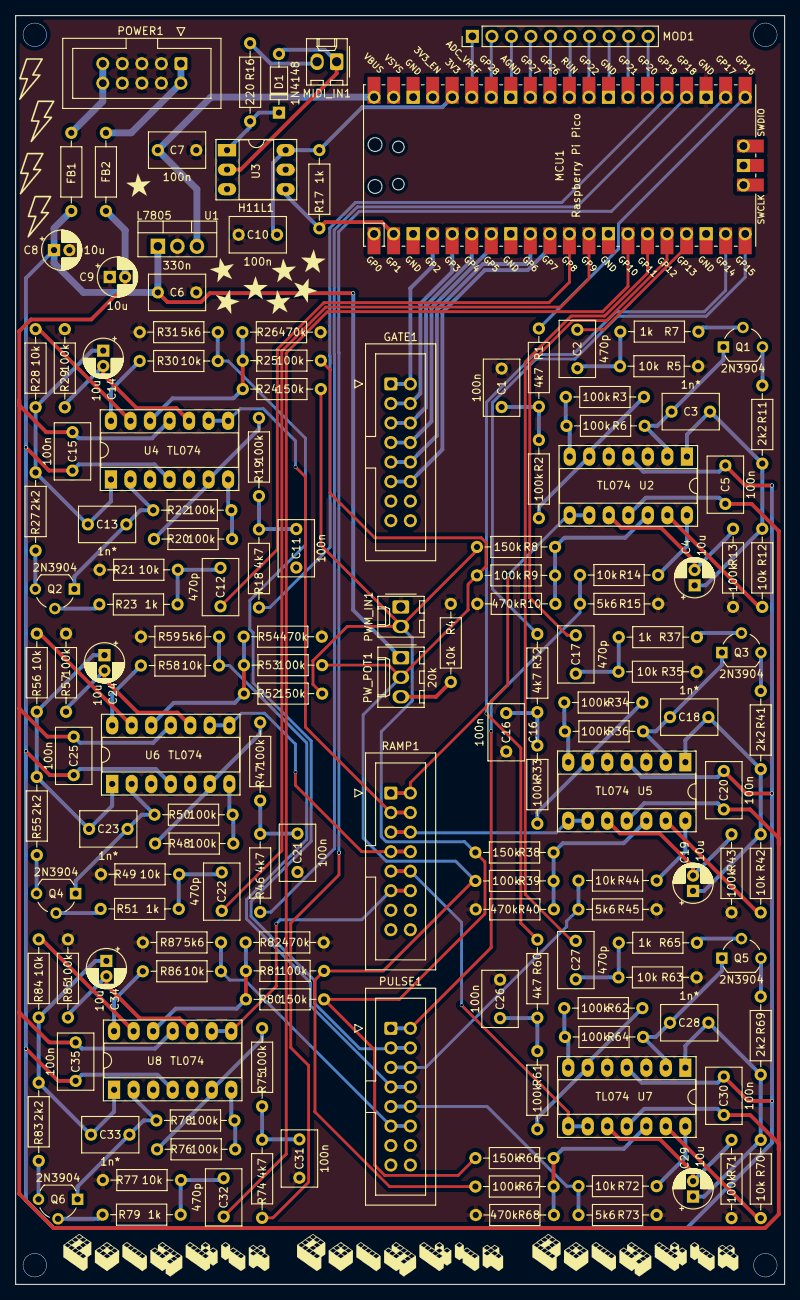
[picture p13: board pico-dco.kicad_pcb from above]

Board: 2 copper layers, 100.0 x 165.0 mm, 148 parts (0 on the bottom side), 126 nets.

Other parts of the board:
U1: L7805; TO-220-3_Vertical

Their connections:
+5V: U1.3; also elsewhere on the board
+12V: U1.1; also elsewhere on the board
GND: U1.2; also elsewhere on the board

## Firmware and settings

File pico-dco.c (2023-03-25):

#include <stdio.h>
#include <stdlib.h>
#include <math.h>
#include "pico/stdlib.h"
#include "hardware/gpio.h"
#include "hardware/adc.h"
#include "hardware/pio.h"
#include "hardware/clocks.h"
#include "pico-dco.pio.h"
#include "hardware/pwm.h"
#include "bsp/board.h"
#include "tusb.h"
#include "hardware/uart.h"

#define NUM_VOICES 6
#define MIDI_CHANNEL 1
#define USE_ADC_STACK_VOICES // gpio 28 (adc 2)
#define USE_ADC_DETUNE       // gpio 27 (adc 1)
#define USE_ADC_FM           // gpio 26 (adc 0)

uint STACK_VOICES = 1;
float DETUNE = 0.0f, LAST_DETUNE = 0.0f;
float FM_VALUE = 0.0f;  
float LAST_FM = 0.0f;

// Scale factor for FM. Controls how intense the effect is at maximum input voltage.
// Units: Hertz.
float FM_INTENSITY = 5.0f;          

const float BASE_NOTE = 440.0f;
const uint8_t RESET_PINS[NUM_VOICES] = {13, 8, 12, 9, 11, 10};
const uint8_t RANGE_PINS[NUM_VOICES] = {16, 19, 15, 18, 14, 17};
const uint8_t GATE_PINS[NUM_VOICES] = {2, 3, 4, 5, 6, 7};
const uint8_t VOICE_TO_PIO[NUM_VOICES] = {0, 0, 0, 0, 1, 1};
const uint8_t VOICE_TO_SM[NUM_VOICES] = {0, 1, 2, 3, 0, 1};
const uint16_t DIV_COUNTER = 1250;
uint8_t RANGE_PWM_SLICES[NUM_VOICES];

uint32_t VOICES[NUM_VOICES];
uint8_t VOICE_NOTES[NUM_VOICES];
uint8_t VOICE_GATE[NUM_VOICES];

uint8_t NEXT_VOICE = 0;
uint32_t LED_BLINK_START = 0;
PIO pio[2] = {pio0, pio1};
uint8_t midi_serial_status = 0;
uint16_t midi_pitch_bend = 0x2000, last_midi_pitch_bend = 0x2000;
bool portamento = false;
uint8_t portamento_time = 0, portamento_start = 0, portamento_stop = 0;
float portamento_cur_freq = 0.0f;

void init_sm(PIO pio, uint sm, uint offset, uint pin);
void set_frequency(PIO pio, uint sm, float freq);
float get_freq_from_midi_note(uint8_t note);
void led_blinking_task();
uint8_t get_free_voice();
void usb_midi_task();
void serial_midi_task();
void note_on(uint8_t note, uint8_t velocity);
void note_off(uint8_t note);
void voice_task();
void adc_task();
long map(long x, long in_min, long in_max, long out_min, long out_max);

int main() {
    board_init();
    tusb_init();

    // use more accurate PWM mode for buck-boost converter
    gpio_init(23);
    gpio_set_dir(23, GPIO_OUT);
    gpio_put(23, 1);

    // init serial midi
    uart_init(uart0, 31250);
    uart_set_fifo_enabled(uart0, true);
    gpio_set_function(0, GPIO_FUNC_UART);
    gpio_set_function(1, GPIO_FUNC_UART);

    // pwm init
    for (int i=0; i<NUM_VOICES; i++) {
        gpio_set_function(RANGE_PINS[i], GPIO_FUNC_PWM);
        RANGE_PWM_SLICES[i] = pwm_gpio_to_slice_num(RANGE_PINS[i]);
        pwm_set_wrap(RANGE_PWM_SLICES[i], DIV_COUNTER);
        pwm_set_enabled(RANGE_PWM_SLICES[i], true);
    }

    // pio init
    uint offset[2];
    offset[0] = pio_add_program(pio[0], &frequency_program);
    offset[1] = pio_add_program(pio[1], &frequency_program);
    for (int i=0; i<NUM_VOICES; i++) {
        init_sm(pio[VOICE_TO_PIO[i]], VOICE_TO_SM[i], offset[VOICE_TO_PIO[i]], RESET_PINS[i]);
    }

    // gate gpio init
    for (int i=0; i<NUM_VOICES; i++) {
        gpio_init(GATE_PINS[i]);
        gpio_set_dir(GATE_PINS[i], GPIO_OUT);
    }

    // adc init
    #if defined(USE_ADC_STACK_VOICES) || defined(USE_ADC_DETUNE) || defined(USE_ADC_FM) 
    adc_init();
    #ifdef USE_ADC_DETUNE
    adc_gpio_init(27);
    #endif
    #ifdef USE_ADC_STACK_VOICES
    adc_gpio_init(28);
    #endif
    #ifdef USE_ADC_FM
    adc_gpio_init(26);
    #endif
    #endif

    // init voices
    for (int i=0; i<NUM_VOICES; i++) {
        VOICES[i] = 0;
        VOICE_GATE[i] = 0;
    }

    while (1) {
        tud_task();
        usb_midi_task();
        serial_midi_task();
        voice_task();
        #if defined(USE_ADC_STACK_VOICES) || defined(USE_ADC_DETUNE) || defined(USE_ADC_FM)
        adc_task();
        #endif
        led_blinking_task();
    }
}

void init_sm(PIO pio, uint sm, uint offset, uint pin) {
    init_sm_pin(pio, sm, offset, pin);
    pio_sm_set_enabled(pio, sm, true);
}

void set_frequency(PIO pio, uint sm, float freq) {
    uint32_t clk_div = clock_get_hz(clk_sys) / 2 / freq;
    if (freq == 0) clk_div = 0;
    pio_sm_put(pio, sm, clk_div);
    pio_sm_exec(pio, sm, pio_encode_pull(false, false));
    pio_sm_exec(pio, sm, pio_encode_out(pio_y, 32));
}

float get_freq_from_midi_note(uint8_t note) {
    if (portamento && portamento_start != 0 && portamento_stop != 0) {
        float freq1 = pow(2, (portamento_start-69)/12.0f) * BASE_NOTE;
        float freq2 = pow(2, (portamento_stop-69)/12.0f) * BASE_NOTE;
        if (portamento_cur_freq == 0) {
            portamento_cur_freq = freq1;
        } else {
            if (freq1 < freq2) {
                portamento_cur_freq += 1.0f/(portamento_time+1);
                if (portamento_cur_freq > freq2) portamento_cur_freq = freq2;
            } else {
                portamento_cur_freq -= 1.0f/(portamento_time+1);
                if (portamento_cur_freq < freq2) portamento_cur_freq = freq2;
            }
        }
        return portamento_cur_freq;
    }

    return pow(2, (note-69)/12.0f) * BASE_NOTE;
}

void usb_midi_task() {
    if (tud_midi_available() < 4) return;

    uint8_t buff[4];

    LED_BLINK_START = board_millis();
    board_led_write(true);

    if (tud_midi_packet_read(buff)) {
        if (buff[1] == (0x90 | (MIDI_CHANNEL-1))) {
            if (buff[3] > 0) {
                note_on(buff[2], buff[3]);
            } else {
                note_off(buff[2]);
            }
        }

        if (buff[1] == (0x80 | (MIDI_CHANNEL-1))) {
            note_off(buff[2]);
        }

        if (buff[1] == (0xE0 | (MIDI_CHANNEL-1))) {
            midi_pitch_bend = buff[2] | (buff[3]<<7);
        }

        if (midi_serial_status == (0xB0 | (MIDI_CHANNEL-1))) {
            if (buff[2] == 5) { // portamento time
                portamento_time = buff[3];
            }
            if (buff[2] == 65) { // portamento on/off
                portamento = buff[3] > 63;
            }
        }
    }
}

void serial_midi_task() {
    if (!uart_is_readable(uart0)) return;

    uint8_t lsb = 0, msb = 0;

    uint8_t data = uart_getc(uart0);
    
    LED_BLINK_START = board_millis();
    board_led_write(true);

    // status
    if (data >= 0xF0 && data <= 0xF7) {
        midi_serial_status = 0;
        return;
    }

    // realtime message
    if (data >= 0xF8 && data <= 0xFF) {
        return;
    }

    if (data >= 0x80 && data <= 0xEF) {
        midi_serial_status = data;
    }

    if (midi_serial_status >= 0x80 && midi_serial_status <= 0x9F ||
        midi_serial_status >= 0xB0 && midi_serial_status <= 0xBF || // cc messages
        midi_serial_status >= 0xE0 && midi_serial_status <= 0xEF) {

        lsb = uart_getc(uart0);
        msb = uart_getc(uart0);
    }

    if (midi_serial_status == (0x90 | (MIDI_CHANNEL-1))) {
        if (msb > 0) {
            note_on(lsb, msb);
        } else {
            note_off(lsb);
        }
    }

    if (midi_serial_status == (0x80 | (MIDI_CHANNEL-1))) {
        note_off(lsb);
    }

    if (midi_serial_status == (0xE0 | (MIDI_CHANNEL-1))) {
        midi_pitch_bend = lsb | (msb<<7);
    }

    if (midi_serial_status == (0xB0 | (MIDI_CHANNEL-1))) {
        if (lsb == 5) { // portamento time
            portamento_time = msb;
        }
        if (lsb == 65) { // portamento on/off
             portamento = msb > 63;
        }
    }
}

void note_on(uint8_t note, uint8_t velocity) {
    if (STACK_VOICES < 2) {
        for (int i=0; i<NUM_VOICES; i++) {
            if (VOICE_NOTES[i] == note && VOICE_GATE[i]) return; // note already playing
        }
    }
    for (int i=0; i<STACK_VOICES; i++) {
        uint8_t voice_num = get_free_voice();

        VOICES[voice_num] = board_millis();
        VOICE_NOTES[voice_num] = note;
        VOICE_GATE[voice_num] = 1;

        float freq = get_freq_from_midi_note(note) * (1 + (pow(-1, i) * DETUNE));
        set_frequency(pio[VOICE_TO_PIO[voice_num]], VOICE_TO_SM[voice_num], freq);
        // amplitude adjustment
        pwm_set_chan_level(RANGE_PWM_SLICES[voice_num], pwm_gpio_to_channel(RANGE_PINS[voice_num]), (int)(DIV_COUNTER*(freq*0.00025f-1/(100*freq))));
        // gate on
        gpio_put(GATE_PINS[voice_num], 1);
    }
    if (portamento) {
        if (portamento_start == 0) {
            portamento_start = note;
            portamento_cur_freq = 0.0f;
        } else {
            portamento_stop = note;
        }
    }
    last_midi_pitch_bend = 0;
}

void note_off(uint8_t note) {
    // gate off
    for (int i=0; i<NUM_VOICES; i++) {
        if (VOICE_NOTES[i] == note) {
            gpio_put(GATE_PINS[i], 0);

            //VOICE_NOTES[i] = 0;
            VOICES[i] = 0;
            VOICE_GATE[i] = 0;
        }
    }
    if (portamento_stop == note) {
        portamento_start = portamento_stop;
        portamento_stop = 0;
        portamento_cur_freq = 0.0f;
    }
    /*
    if (portamento_start == note) {
        portamento_stop = 0;
        portamento_cur_freq = 0.0f;
    }
    */
}

uint8_t get_free_voice() {
    uint32_t oldest_time = board_millis();
    uint8_t oldest_voice = 0;

    for (int i=0; i<NUM_VOICES; i++) {
        uint8_t n = (NEXT_VOICE+i)%NUM_VOICES;

        if (VOICE_GATE[n] == 0) {
            NEXT_VOICE = (n+1)%NUM_VOICES;
            return n;
        }

        if (VOICES[i]<oldest_time) {
            oldest_time = VOICES[i];
            oldest_voice = i;
        }
    }

    NEXT_VOICE = (oldest_voice+1)%NUM_VOICES;
    return oldest_voice;
}

void voice_task() {
    if (midi_pitch_bend != last_midi_pitch_bend || DETUNE != LAST_DETUNE || portamento || FM_VALUE != LAST_FM) {

        last_midi_pitch_bend = midi_pitch_bend;
        LAST_DETUNE = DETUNE;
        LAST_FM = FM_VALUE;

        for (int i=0; i<NUM_VOICES; i++) {

            float freq = get_freq_from_midi_note(VOICE_NOTES[i]) * (1 + (pow(-1, i) * DETUNE));

            freq += FM_VALUE * FM_INTENSITY; // Add linear frequency modulation
            
            freq = freq-(freq*((0x2000-midi_pitch_bend)/67000.0f));
            set_frequency(pio[VOICE_TO_PIO[i]], VOICE_TO_SM[i], freq);
            pwm_set_chan_level(RANGE_PWM_SLICES[i], pwm_gpio_to_channel(RANGE_PINS[i]), (int)(DIV_COUNTER*(freq*0.00025f-1/(100*freq))));
        }
    }
}

void adc_task() {
    uint16_t raw;

    #ifdef USE_ADC_DETUNE
    adc_select_input(1);
    raw = adc_read();
    DETUNE = map(raw, 0, 4095, 0, 50)/1000.0f;
    #endif

    #ifdef USE_ADC_STACK_VOICES
    adc_select_input(2);
    raw = adc_read();
    STACK_VOICES = map(raw, 0, 4000, 1, NUM_VOICES);
    #endif

    #ifdef USE_ADC_FM

    adc_select_input(0);
    raw = adc_read();

    // This input assumes a centre FM value of 2^11 = 2048, as the 
    // ADCs are unsigned. This can be overcome in hardware with a fixed 
    // voltage offset. The range of the Pico's ADCs is 3.3V, so a fixed 
    // offset of 1.65V is needed.
    int signed_raw = raw - (1 << 11);
    FM_VALUE = (float) signed_raw / (float) (1 << 11);
    #endif

}

long map(long x, long in_min, long in_max, long out_min, long out_max) {
  return (x - in_min) * (out_max - out_min) / (in_max - in_min) + out_min;
}

void led_blinking_task() {
    if (board_millis() - LED_BLINK_START < 50) return;
    board_led_write(false);
}

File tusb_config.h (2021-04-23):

/*
 * The MIT License (MIT)
 *
 * Copyright (c) 2019 Ha Thach (tinyusb.org)
 *
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
 */

#ifndef _TUSB_CONFIG_H_
#define _TUSB_CONFIG_H_

#ifdef __cplusplus
extern "C" {
#endif

//--------------------------------------------------------------------
// COMMON CONFIGURATION
//--------------------------------------------------------------------

// defined by compiler flags for flexibility
#ifndef CFG_TUSB_MCU
#error CFG_TUSB_MCU must be defined
#endif

#if CFG_TUSB_MCU == OPT_MCU_LPC18XX || CFG_TUSB_MCU == OPT_MCU_LPC43XX || CFG_TUSB_MCU == OPT_MCU_MIMXRT10XX || \
    CFG_TUSB_MCU == OPT_MCU_NUC505 || CFG_TUSB_MCU == OPT_MCU_CXD56
#define CFG_TUSB_RHPORT0_MODE     (OPT_MODE_DEVICE | OPT_MODE_HIGH_SPEED)
#else
#define CFG_TUSB_RHPORT0_MODE     OPT_MODE_DEVICE
#endif

#ifndef CFG_TUSB_OS
#define CFG_TUSB_OS                 OPT_OS_PICO
#endif

// CFG_TUSB_DEBUG is defined by compiler in DEBUG build
// #define CFG_TUSB_DEBUG           0

/* USB DMA on some MCUs can only access a specific SRAM region with restriction on alignment.
 * Tinyusb use follows macros to declare transferring memory so that they can be put
 * into those specific section.
 * e.g
 * - CFG_TUSB_MEM SECTION : __attribute__ (( section(".usb_ram") ))
 * - CFG_TUSB_MEM_ALIGN   : __attribute__ ((aligned(4)))
 */
#ifndef CFG_TUSB_MEM_SECTION
#define CFG_TUSB_MEM_SECTION
#endif

#ifndef CFG_TUSB_MEM_ALIGN
#define CFG_TUSB_MEM_ALIGN          __attribute__ ((aligned(4)))
#endif

//--------------------------------------------------------------------
// DEVICE CONFIGURATION
//--------------------------------------------------------------------

#ifndef CFG_TUD_ENDPOINT0_SIZE
#define CFG_TUD_ENDPOINT0_SIZE    64
#endif

//------------- CLASS -------------//
#define CFG_TUD_CDC             0
#define CFG_TUD_MSC             0
#define CFG_TUD_HID             0 
#define CFG_TUD_MIDI            1 
#define CFG_TUD_VENDOR          0

// MIDI FIFO size of TX and RX
#define CFG_TUD_MIDI_RX_BUFSIZE   (TUD_OPT_HIGH_SPEED ? 512 : 64)
#define CFG_TUD_MIDI_TX_BUFSIZE   (TUD_OPT_HIGH_SPEED ? 512 : 64)

#ifdef __cplusplus
}
#endif

#endif /* _TUSB_CONFIG_H_ */

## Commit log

2021-04-23 Initial import
    [pico-dco.kicad_pcb, pico-dco.sch]
2021-05-22 Add 6 voices and serial midi to kicad schematics/PCB
    [Pico-DCO-1.sch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]
2021-05-22 Update silk screen
    [Pico-DCO-1.sch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]
2021-05-23 Changed 5V regulator to L7805
    [Pico-DCO-1.sch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]
2021-05-23 Add polyphony, update readme
    [Pico-DCO-1.sch, pico-dco.sch]
2021-06-26 Fix midi running state, add pitch bend
    [pico-dco.c]
2021-10-30 Fix next free voice
    [pico-dco.c]
2021-12-12 Add voice stacking/detuning on adc readings
2022-08-07 Fixed voice gate when MIDI note on is received
    [pico-dco.c]
2022-11-07 Add adc section to readme
2023-03-25 Fix usb midi channels #4
    [pico-dco.c]
